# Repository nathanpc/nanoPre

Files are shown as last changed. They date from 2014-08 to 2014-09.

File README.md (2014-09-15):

# nanoPre

A simple, battery powered, HiFi preamp.

PCB Layout

## Schematics

This is the pre-amplifier. As you can see it's extremely simple and it's designed to be able to fit in any enclosure (but it was designed to fit inside [this one](http://www.aliexpress.com/item/Aluminum-Project-Box-Enclousure-Case-Electronic-DIY-Power-amplifier-aluminum-shell-PCB-shell-power-instrument-shell/1799375798.html)).

Pre-Amplifier

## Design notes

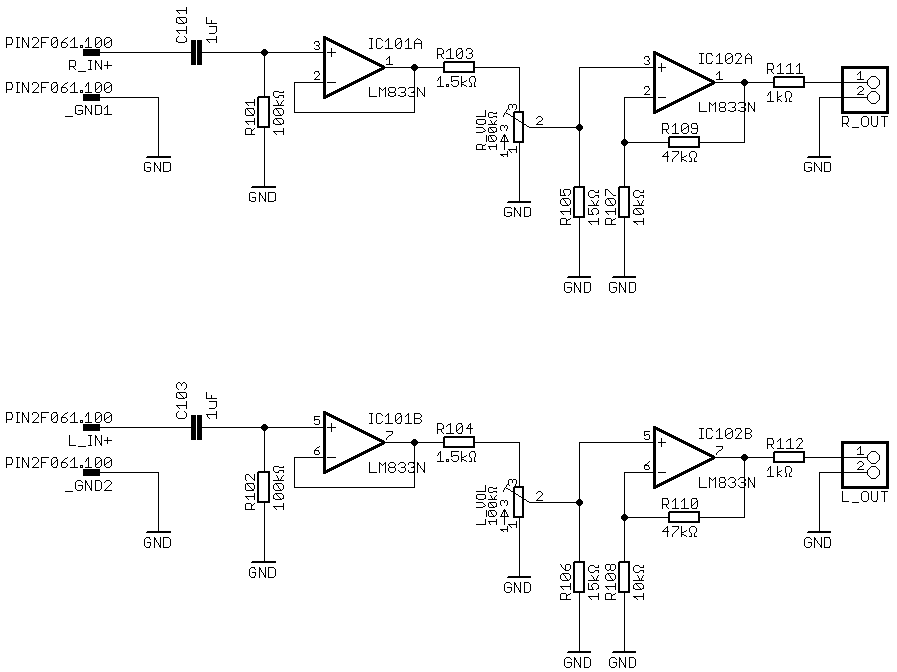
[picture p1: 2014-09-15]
images/RevB-Pre-Amp.png

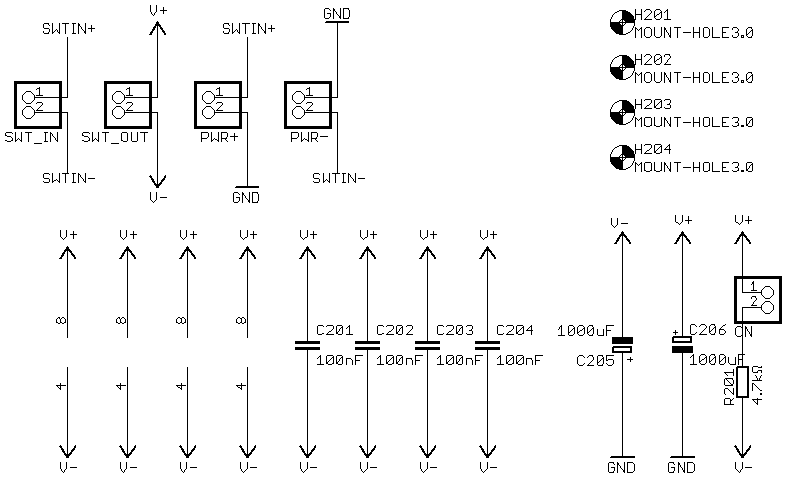
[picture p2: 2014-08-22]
images/RevA-Power-Supply.png

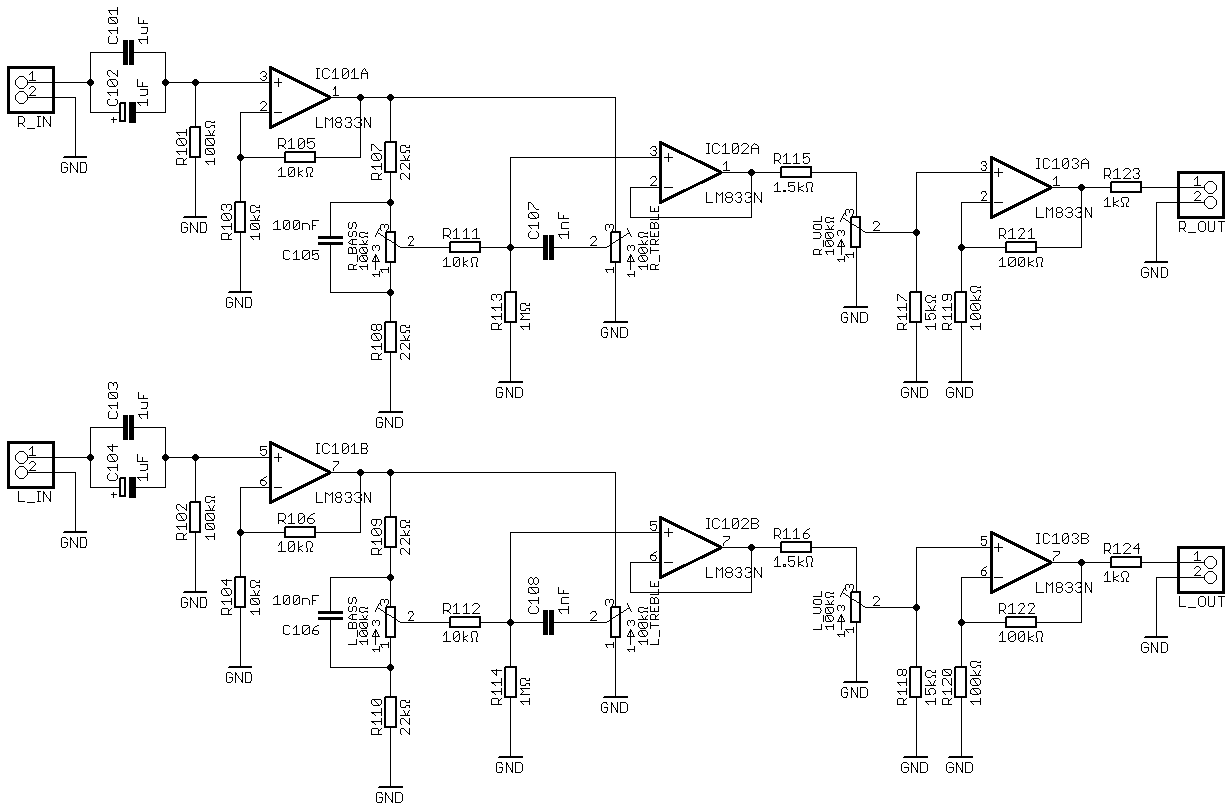
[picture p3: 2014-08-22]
images/RevA-Pre-Amp.png

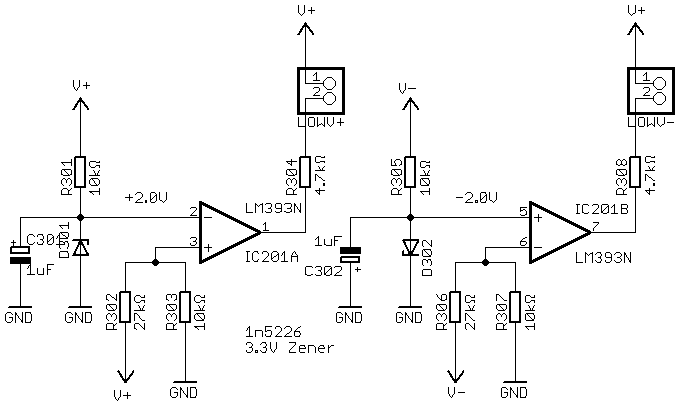
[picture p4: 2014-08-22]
images/RevA-LowV-Detector.png

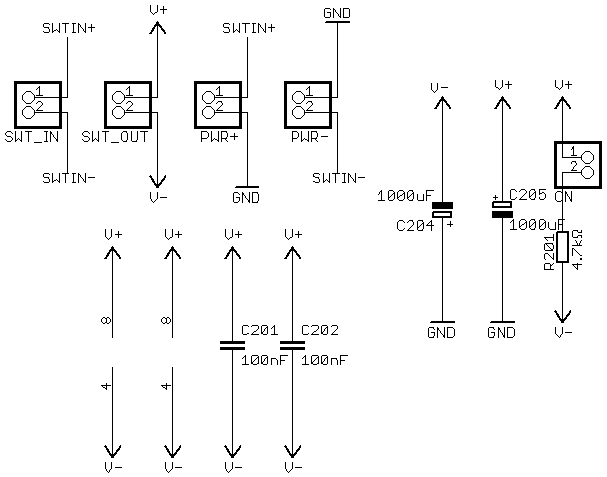
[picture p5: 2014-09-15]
images/RevB-Power-Supply.png

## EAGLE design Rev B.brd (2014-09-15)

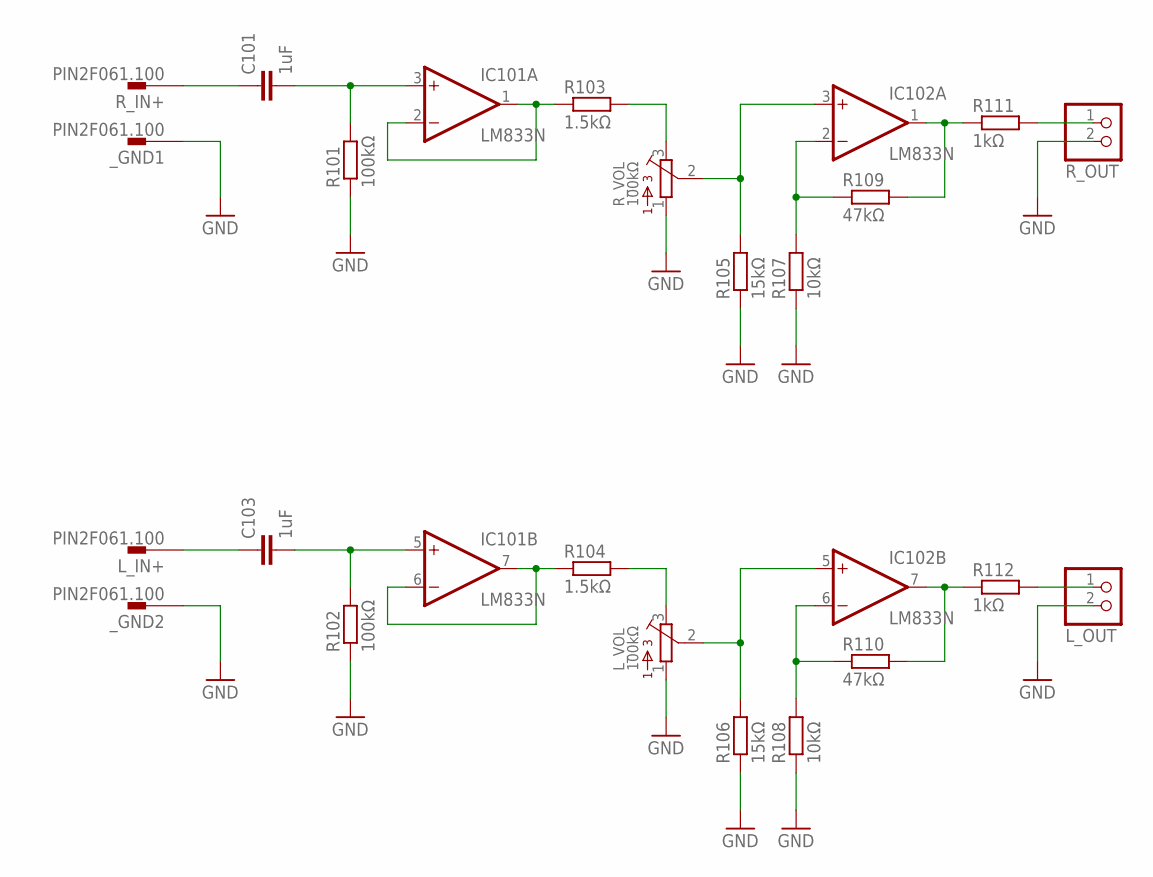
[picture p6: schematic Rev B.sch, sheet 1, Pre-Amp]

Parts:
C101, C103: 1uF; C150-072X183
IC101, IC102: LM833N; DIL08
L_IN+: PIN2F061.100; F061.100
L_OUT: JST_2PIN-THM; JST-PH-2-THM
L_VOL: 100kΩ; 3362U
R101, R102: 100kΩ; 0207/10
R103, R104: 1.5kΩ; 0207/10
R105, R106: 15kΩ; 0207/10
R107, R108: 10kΩ; 0207/10
R109, R110: 47kΩ; 0207/10
R111, R112: 1kΩ; 0207/10
R_IN+: PIN2F061.100; F061.100
R_OUT: JST_2PIN-THM; JST-PH-2-THM
R_VOL: 100kΩ; 3362U
_GND1, _GND2: PIN2F061.100; F061.100

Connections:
GND: L_OUT.2 (1), L_VOL.1, R101.1, R102.1, R105.1, R106.1, R107.1, R108.1, R_OUT.2 (1), R_VOL.1, _GND1.A1, _GND1.A2, _GND2.A1, _GND2.A2; also elsewhere on the board
unnamed: L_OUT.1 (2), R112.2
unnamed: R111.2, R_OUT.1 (2)
unnamed: C101.2, IC101.3 (+IN), R101.2
unnamed: C103.2, IC101.5 (+IN), R102.2
unnamed: C101.1, R_IN+.A1, R_IN+.A2
unnamed: C103.1, L_IN+.A1, L_IN+.A2
unnamed: IC101.1 (OUT), IC101.2 (-IN), R103.1
unnamed: IC102.3 (+IN), R105.2, R_VOL.2
unnamed: R103.2, R_VOL.3
unnamed: IC102.2 (-IN), R107.2, R109.1
unnamed: IC102.1 (OUT), R109.2, R111.1
unnamed: IC101.6 (-IN), IC101.7 (OUT), R104.1
unnamed: IC102.5 (+IN), L_VOL.2, R106.2
unnamed: L_VOL.3, R104.2
unnamed: IC102.6 (-IN), R108.2, R110.1
unnamed: IC102.7 (OUT), R110.2, R112.1

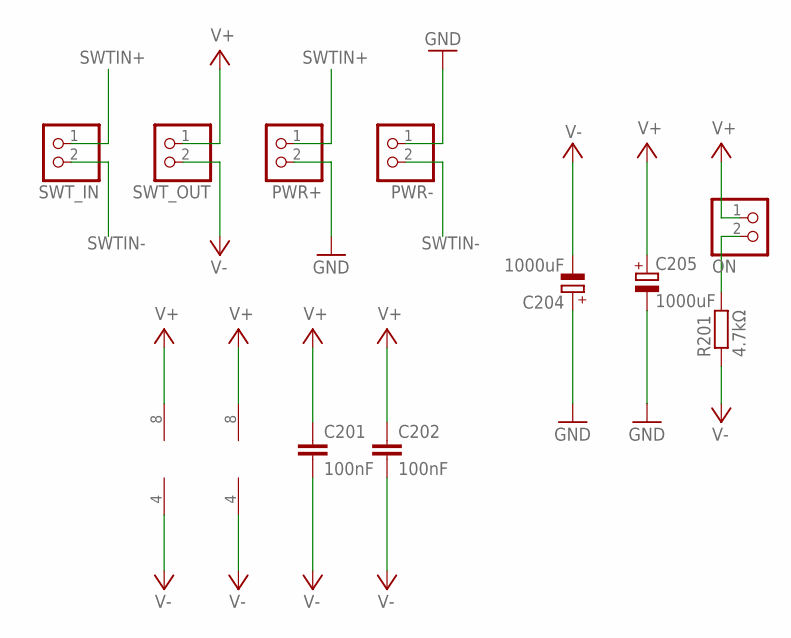
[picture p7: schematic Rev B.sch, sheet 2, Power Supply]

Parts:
C201, C202: 100nF; C025-025X050
C204, C205: 1000uF; E5-10,5
IC101, IC102: LM833N; DIL08
ON: JST_2PIN-THM; JST-PH-2-THM
PWR+: JST_2PIN-THM; JST-PH-2-THM
PWR-: JST_2PIN-THM; JST-PH-2-THM
R201: 4.7kΩ; 0207/10
SWT_IN: JST_2PIN-THM; JST-PH-2-THM
SWT_OUT: JST_2PIN-THM; JST-PH-2-THM

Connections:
GND: C204.+, C205.-, PWR+.2 (1), PWR-.1 (2); also elsewhere on the board
unnamed: ON.2 (1), R201.2
SWTIN+: PWR+.1 (2), SWT_IN.1 (2)
SWTIN-: PWR-.2 (1), SWT_IN.2 (1)
V+: C201.1, C202.1, C205.+, IC101.8 (V+), IC102.8 (V+), ON.1 (2), SWT_OUT.1 (2)
V-: C201.2, C202.2, C204.-, IC101.4 (V-), IC102.4 (V-), R201.1, SWT_OUT.2 (1)

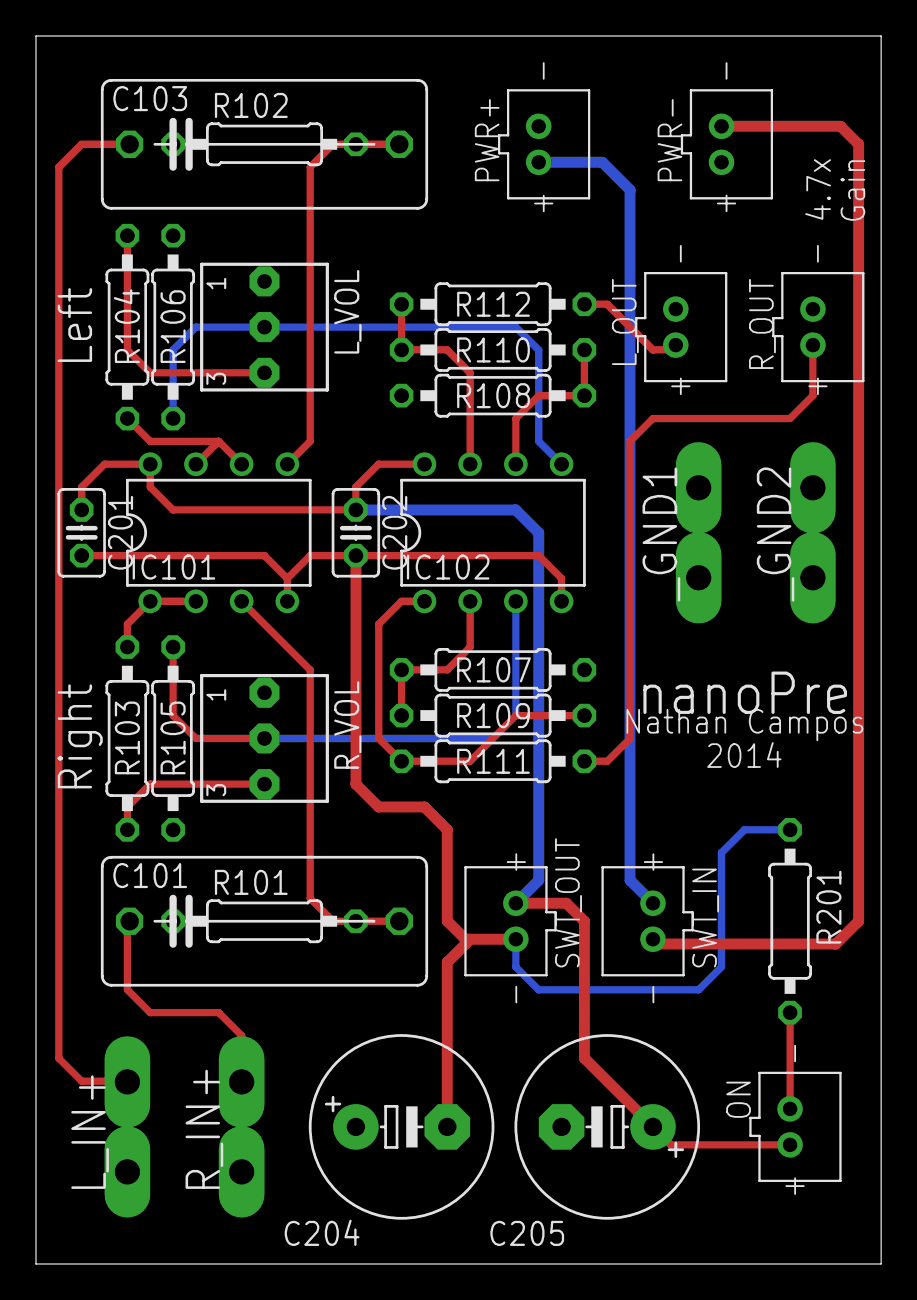
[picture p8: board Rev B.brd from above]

Board: 2 copper layers, 47.0 x 68.2 mm, 34 parts (0 on the bottom side), 22 nets.

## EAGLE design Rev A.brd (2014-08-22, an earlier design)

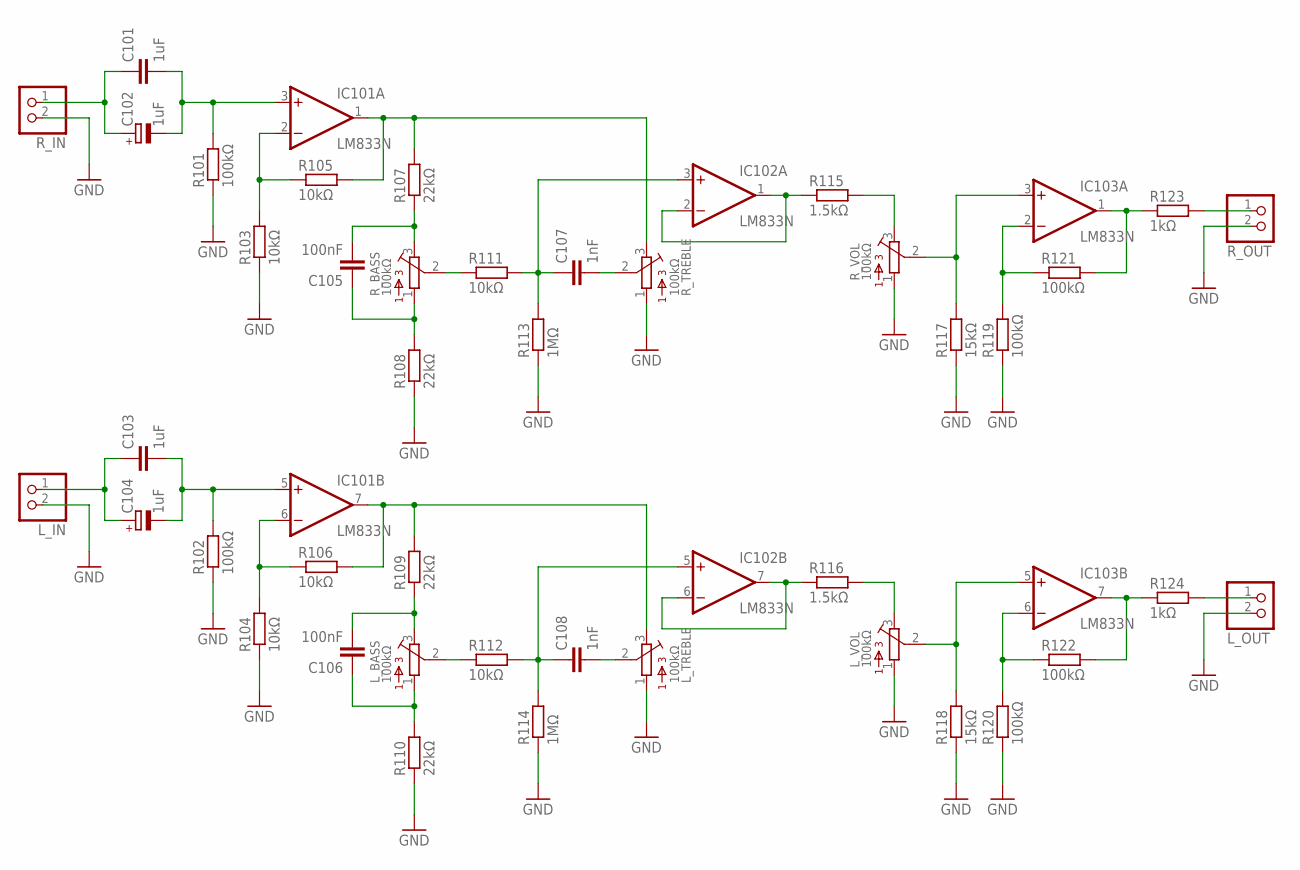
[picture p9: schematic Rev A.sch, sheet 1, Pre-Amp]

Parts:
C101, C103: 1uF; C150-072X183
C102, C104: 1uF; E2-5
C105, C106: 100nF; C050-025X075
C107, C108: 1nF; C050-025X075
IC101, IC102, IC103: LM833N; DIL08
L_BASS: 100kΩ; 3362U
L_IN: JST_2PIN-THM; JST-PH-2-THM
L_OUT: JST_2PIN-THM; JST-PH-2-THM
L_TREBLE: 100kΩ; 3362U
L_VOL: 100kΩ; 3362U
R101, R102, R119, R120, R121, R122: 100kΩ; 0207/10
R103, R104, R105, R106, R111, R112: 10kΩ; 0207/10
R107, R108, R109, R110: 22kΩ; 0207/10
R113, R114: 1MΩ; 0207/10
R115, R116: 1.5kΩ; 0207/10
R117, R118: 15kΩ; 0207/10
R123, R124: 1kΩ; 0207/10
R_BASS: 100kΩ; 3362U
R_IN: JST_2PIN-THM; JST-PH-2-THM
R_OUT: JST_2PIN-THM; JST-PH-2-THM
R_TREBLE: 100kΩ; 3362U
R_VOL: 100kΩ; 3362U

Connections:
GND: L_IN.2 (1), L_OUT.2 (1), L_TREBLE.1, L_VOL.1, R101.1, R102.1, R103.1, R104.1, R108.1, R110.1, R113.1, R114.1, R117.1, R118.1, R119.1, R120.1, R_IN.2 (1), R_OUT.2 (1), R_TREBLE.1, R_VOL.1; also elsewhere on the board
unnamed: L_OUT.1 (2), R124.2
unnamed: R123.2, R_OUT.1 (2)
unnamed: C101.2, C102.-, IC101.3 (+IN), R101.2
unnamed: C103.2, C104.-, IC101.5 (+IN), R102.2
unnamed: C101.1, C102.+, R_IN.1 (2)
unnamed: C103.1, C104.+, L_IN.1 (2)
unnamed: IC102.1 (OUT), IC102.2 (-IN), R115.1
unnamed: C105.2, R107.1, R_BASS.3
unnamed: IC103.3 (+IN), R117.2, R_VOL.2
unnamed: IC101.2 (-IN), R103.2, R105.1
unnamed: R115.2, R_VOL.3
unnamed: C105.1, R108.2, R_BASS.1
unnamed: IC103.2 (-IN), R119.2, R121.1
unnamed: IC103.1 (OUT), R121.2, R123.1
unnamed: R111.1, R_BASS.2
unnamed: C107.1, IC102.3 (+IN), R111.2, R113.2
unnamed: C107.2, R_TREBLE.2
unnamed: IC102.6 (-IN), IC102.7 (OUT), R116.1
unnamed: IC101.6 (-IN), R104.2, R106.1
unnamed: IC101.1 (OUT), R105.2, R107.2, R_TREBLE.3
unnamed: IC103.5 (+IN), L_VOL.2, R118.2
unnamed: L_VOL.3, R116.2
unnamed: C106.2, L_BASS.3, R109.1
unnamed: C106.1, L_BASS.1, R110.2
unnamed: L_BASS.2, R112.1
unnamed: C108.1, IC102.5 (+IN), R112.2, R114.2
unnamed: C108.2, L_TREBLE.2
unnamed: IC101.7 (OUT), L_TREBLE.3, R106.2, R109.2
unnamed: IC103.6 (-IN), R120.2, R122.1
unnamed: IC103.7 (OUT), R122.2, R124.1

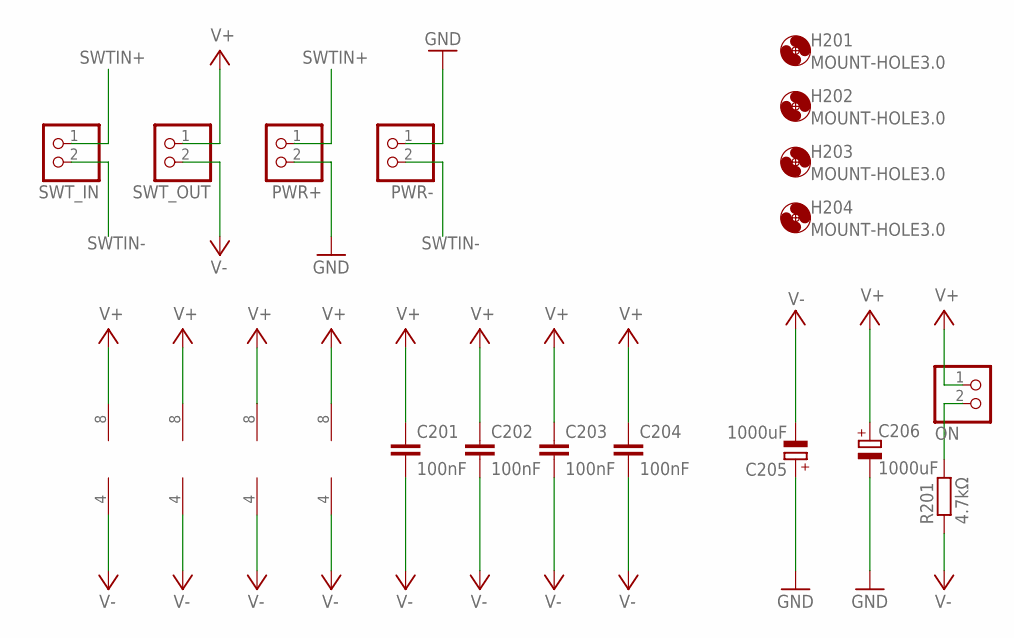
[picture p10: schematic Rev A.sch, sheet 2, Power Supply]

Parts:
C201, C202, C203, C204: 100nF; C025-025X050
C205, C206: 1000uF; E5-10,5
H201, H202, H203, H204: MOUNT-HOLE3.0; 3,0
IC101, IC102, IC103: LM833N; DIL08
IC201: LM393N; DIL08
ON: JST_2PIN-THM; JST-PH-2-THM
PWR+: JST_2PIN-THM; JST-PH-2-THM
PWR-: JST_2PIN-THM; JST-PH-2-THM
R201: 4.7kΩ; 0207/10
SWT_IN: JST_2PIN-THM; JST-PH-2-THM
SWT_OUT: JST_2PIN-THM; JST-PH-2-THM

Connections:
GND: C205.+, C206.-, PWR+.2 (1), PWR-.1 (2); also elsewhere on the board
unnamed: ON.2 (1), R201.2
SWTIN+: PWR+.1 (2), SWT_IN.1 (2)
SWTIN-: PWR-.2 (1), SWT_IN.2 (1)
V+: C201.1, C202.1, C203.1, C204.1, C206.+, IC101.8 (V+), IC102.8 (V+), IC103.8 (V+), IC201.8 (V+), ON.1 (2), SWT_OUT.1 (2); also elsewhere on the board
V-: C201.2, C202.2, C203.2, C204.2, C205.-, IC101.4 (V-), IC102.4 (V-), IC103.4 (V-), IC201.4 (V-), R201.1, SWT_OUT.2 (1); also elsewhere on the board

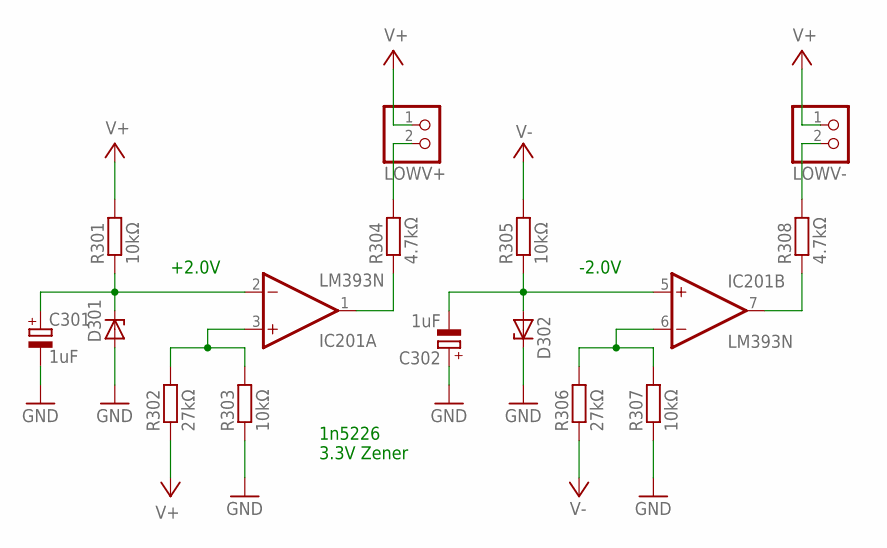
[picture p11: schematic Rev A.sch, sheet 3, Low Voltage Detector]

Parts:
C301, C302: 1uF; E2-5
D301, D302: BZV10; DO34Z7
IC201: LM393N; DIL08
LOWV+: JST_2PIN-THM; JST-PH-2-THM
LOWV-: JST_2PIN-THM; JST-PH-2-THM
R301, R303, R305, R307: 10kΩ; 0207/10
R302, R306: 27kΩ; 0207/10
R304, R308: 4.7kΩ; 0207/10

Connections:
GND: C301.-, C302.+, D301.A, D302.C, R303.1, R307.1; also elsewhere on the board
unnamed: C301.+, D301.C, IC201.2 (-IN), R301.1
unnamed: C302.-, D302.A, IC201.5 (+IN), R305.1
unnamed: LOWV+.2 (1), R304.2
unnamed: IC201.3 (+IN), R302.2, R303.2
unnamed: IC201.6 (-IN), R306.2, R307.2
unnamed: IC201.1 (OUT), R304.1
unnamed: LOWV-.2 (1), R308.2
unnamed: IC201.7 (OUT), R308.1
V+: LOWV+.1 (2), LOWV-.1 (2), R301.2, R302.1; also elsewhere on the board
V-: R305.2, R306.1; also elsewhere on the board

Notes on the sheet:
1n5226 3.3V Zener
+2.0V
-2.0V

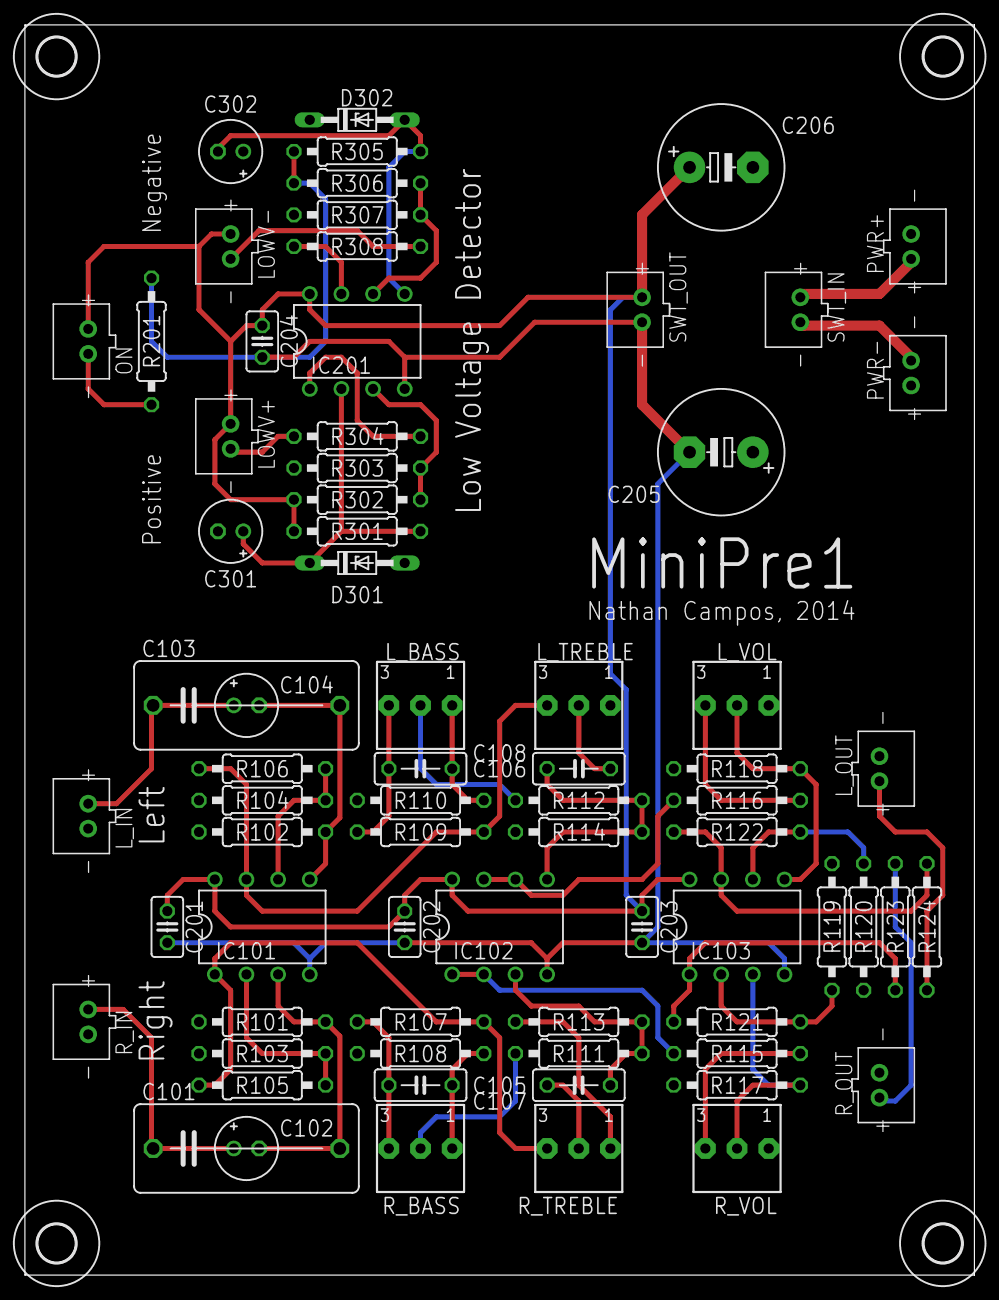
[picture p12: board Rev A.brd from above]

Board: 4 copper layers, 76.2 x 100.3 mm, 76 parts (0 on the bottom side), 44 nets.

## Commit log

2014-08-22 Finished schematic and PCB layout
    [Rev A.brd, Rev A.sch]
2014-08-22 Exported the schematic
2014-09-15 Rev B
    [Rev B.brd, Rev B.sch]
